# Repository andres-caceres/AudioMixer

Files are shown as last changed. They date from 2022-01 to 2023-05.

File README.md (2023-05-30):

# AudioMixer v1.2 (beta)
Digital audio USB controller firmware for Windows, tested using an Arduino Nano. Lets you control the volume of different applications using potentiometers and mute each channel individually using push button switches.
Based on [Deej by Omriharel], can be used with deej.exe Windows client.

## Features
* Includes mute push button functionality and ADC range calibration settings for each channel.
* Supports TM1637 7 segment display for controller position feedback.
* Supports LED push buttons for visual feedback.
* Uses digital filtering to increase potentiometer position accuracy.

## Upcoming (desired) Features
* Windows audio device selection using one push button press.
* Push buttons that can be used for executing Macros to automate tasks.
* Calibration subroutine for sliders

(Work in progress)

[//]: #

[Deej by Omriharel]: <https://github.com/omriharel/deej>

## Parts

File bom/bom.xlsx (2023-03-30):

 | Primer prototipo
No. | Item | Cantidad | Precio unit | Precio total | ¿Se tiene? | Costo total
1 | Resistencia 10k | 5 | S/0.10 | S/0.50 | NO | S/0.50
2 | LED Rojo | 3 | S/0.10 | S/0.30 | NO | S/0.30
3 | Transistor NPN 2N3904 | 2 | S/0.20 | S/0.40 | NO | S/0.40
4 | Encoder Rotativo | 1 | S/7.00 | S/7.00 | NO | S/7.00
 |  |  | Valor Total: | S/8.20 | Inversión Total: | S/8.20
 | Segundo prototipo
No. | Item | Cantidad | Precio unit | Precio total | ¿Se tiene? | Costo total
1 | Resistencia 10k | 5 | S/0.10 | S/0.50 | NO | S/0.50
2 | LED Rojo | 3 | S/0.10 | S/0.30 | NO | S/0.30
3 | Transistor NPN 2N3904 | 2 | S/0.20 | S/0.40 | NO | S/0.40
4 | Encoder Rotativo | 1 | S/7.00 | S/7.00 | NO | S/7.00
 |  |  | Valor Total: | S/8.20 | Inversión Total: | S/8.20

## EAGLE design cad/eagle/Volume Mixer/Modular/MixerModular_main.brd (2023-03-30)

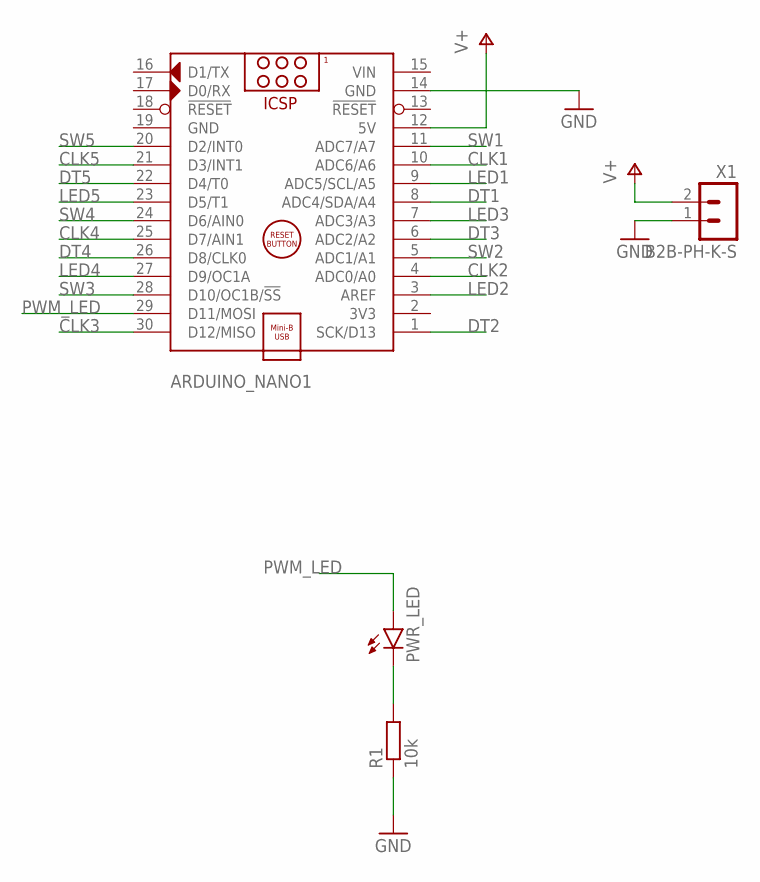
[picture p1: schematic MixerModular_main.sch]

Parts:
ARDUINO_NANO1: ARDUINO_NANO
PWR_LED: LED5MM
R1: 10k; 0207/10
X1: B2B-PH-K-S

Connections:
CLK1: ARDUINO_NANO1.10 (ADC6/A6)
CLK2: ARDUINO_NANO1.4 (ADC0/A0)
CLK3: ARDUINO_NANO1.30 (D12/MISO)
CLK4: ARDUINO_NANO1.25 (D7/AIN1)
CLK5: ARDUINO_NANO1.21 (D3/INT1)
DT1: ARDUINO_NANO1.8 (ADC4/SDA/A4)
DT2: ARDUINO_NANO1.1 (SCK/D13)
DT3: ARDUINO_NANO1.6 (ADC2/A2)
DT4: ARDUINO_NANO1.26 (D8/CLK0)
DT5: ARDUINO_NANO1.22 (D4/T0)
GND: ARDUINO_NANO1.14 (GND), ARDUINO_NANO1.19 (GND), R1.1, X1.1
LED1: ARDUINO_NANO1.9 (ADC5/SCL/A5)
LED2: ARDUINO_NANO1.3 (AREF)
LED3: ARDUINO_NANO1.7 (ADC3/A3)
LED4: ARDUINO_NANO1.27 (D9/OC1A)
LED5: ARDUINO_NANO1.23 (D5/T1)
unnamed: PWR_LED.K (C), R1.2
PWM_LED: ARDUINO_NANO1.29 (D11/MOSI), PWR_LED.A
SW1: ARDUINO_NANO1.11 (ADC7/A7)
SW2: ARDUINO_NANO1.5 (ADC1/A1)
SW3: ARDUINO_NANO1.28 (D10/OC1B/!SS)
SW4: ARDUINO_NANO1.24 (D6/AIN0)
SW5: ARDUINO_NANO1.20 (D2/INT0)
V+: ARDUINO_NANO1.12 (5V), X1.2
VIN: ARDUINO_NANO1.15 (VIN)

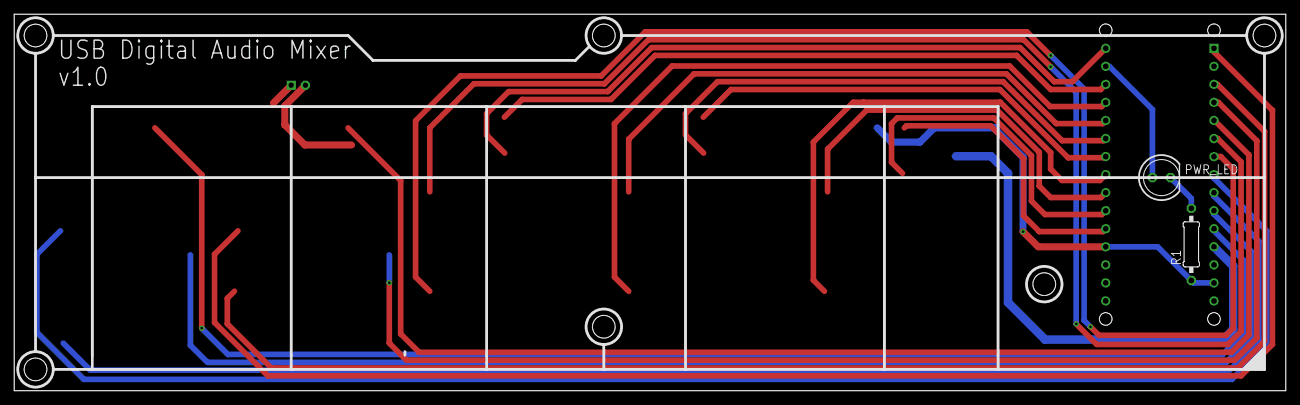
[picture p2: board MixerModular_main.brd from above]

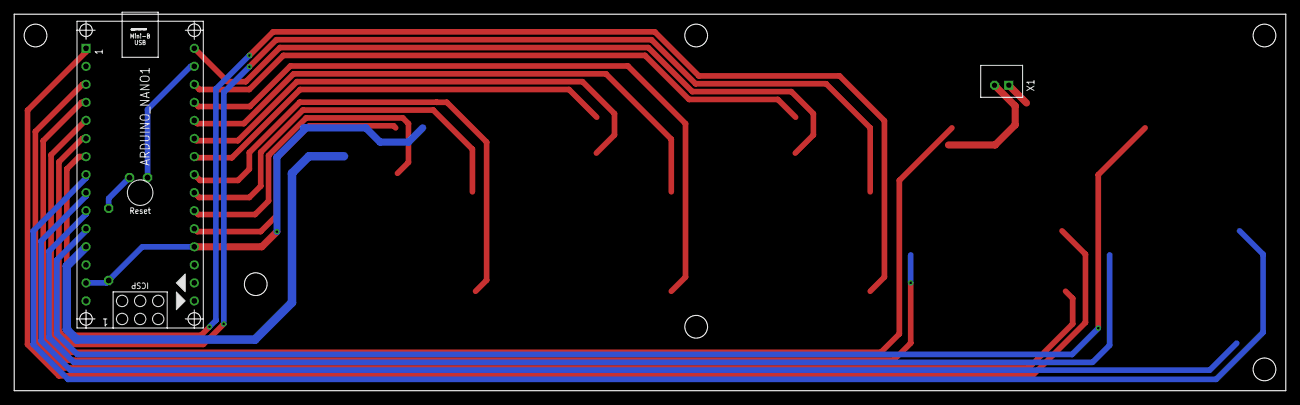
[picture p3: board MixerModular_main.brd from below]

Board: 2 copper layers, 179.0 x 53.0 mm, 4 parts (2 on the bottom side), 4 nets.

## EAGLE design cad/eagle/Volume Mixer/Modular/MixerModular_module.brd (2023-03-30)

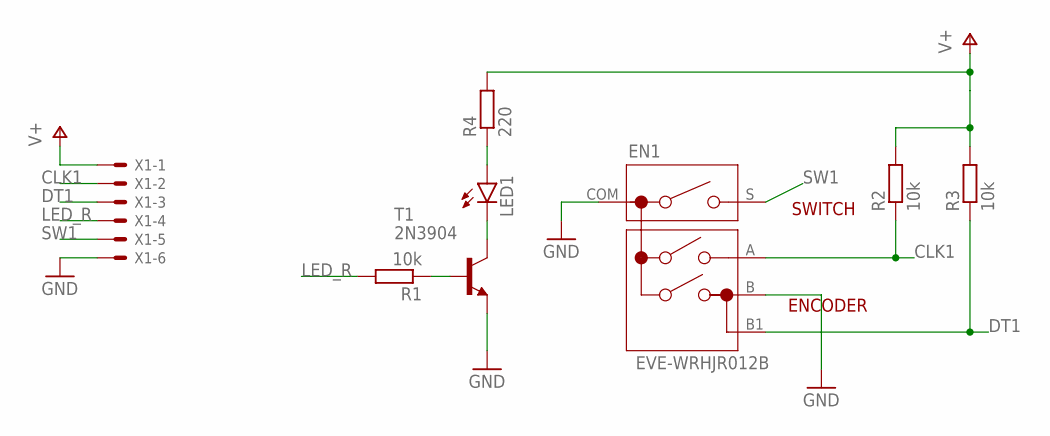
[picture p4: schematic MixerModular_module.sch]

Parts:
EN1: EVE-WRHJR012B
LED1: LED5MM
R1, R2, R3: 10k; 0207/10
R4: 220; 0207/10
T1: 2N3904; TO92
X1: 22-23-2061

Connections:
CLK1: EN1.A, R2.1, X1.2
DT1: EN1.B1, R3.1, X1.3
GND: EN1.B, EN1.COM, T1.3 (E), X1.6
LED_R: R1.2, X1.4
unnamed: LED1.A, R4.1
unnamed: R1.1, T1.2 (B)
unnamed: LED1.K (C), T1.1 (C)
SW1: EN1.S, X1.5
V+: R2.2, R3.2, R4.2, X1.1

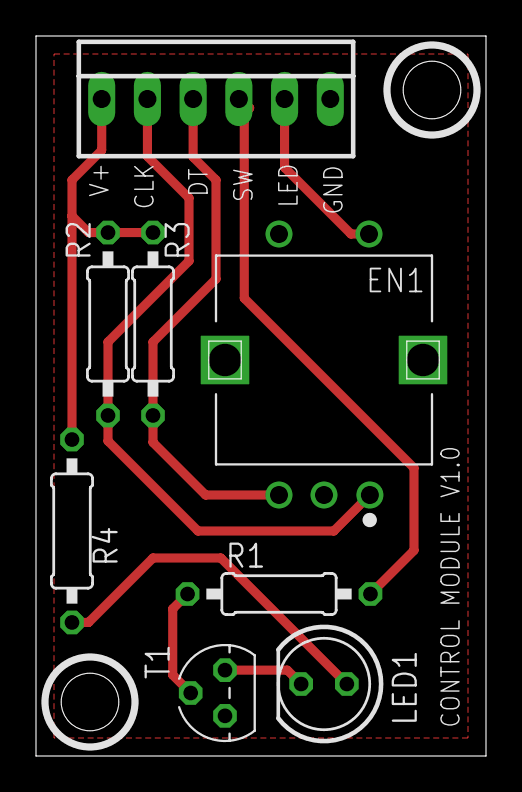
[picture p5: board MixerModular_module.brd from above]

Board: 2 copper layers, 25.0 x 40.0 mm, 8 parts (0 on the bottom side), 9 nets.

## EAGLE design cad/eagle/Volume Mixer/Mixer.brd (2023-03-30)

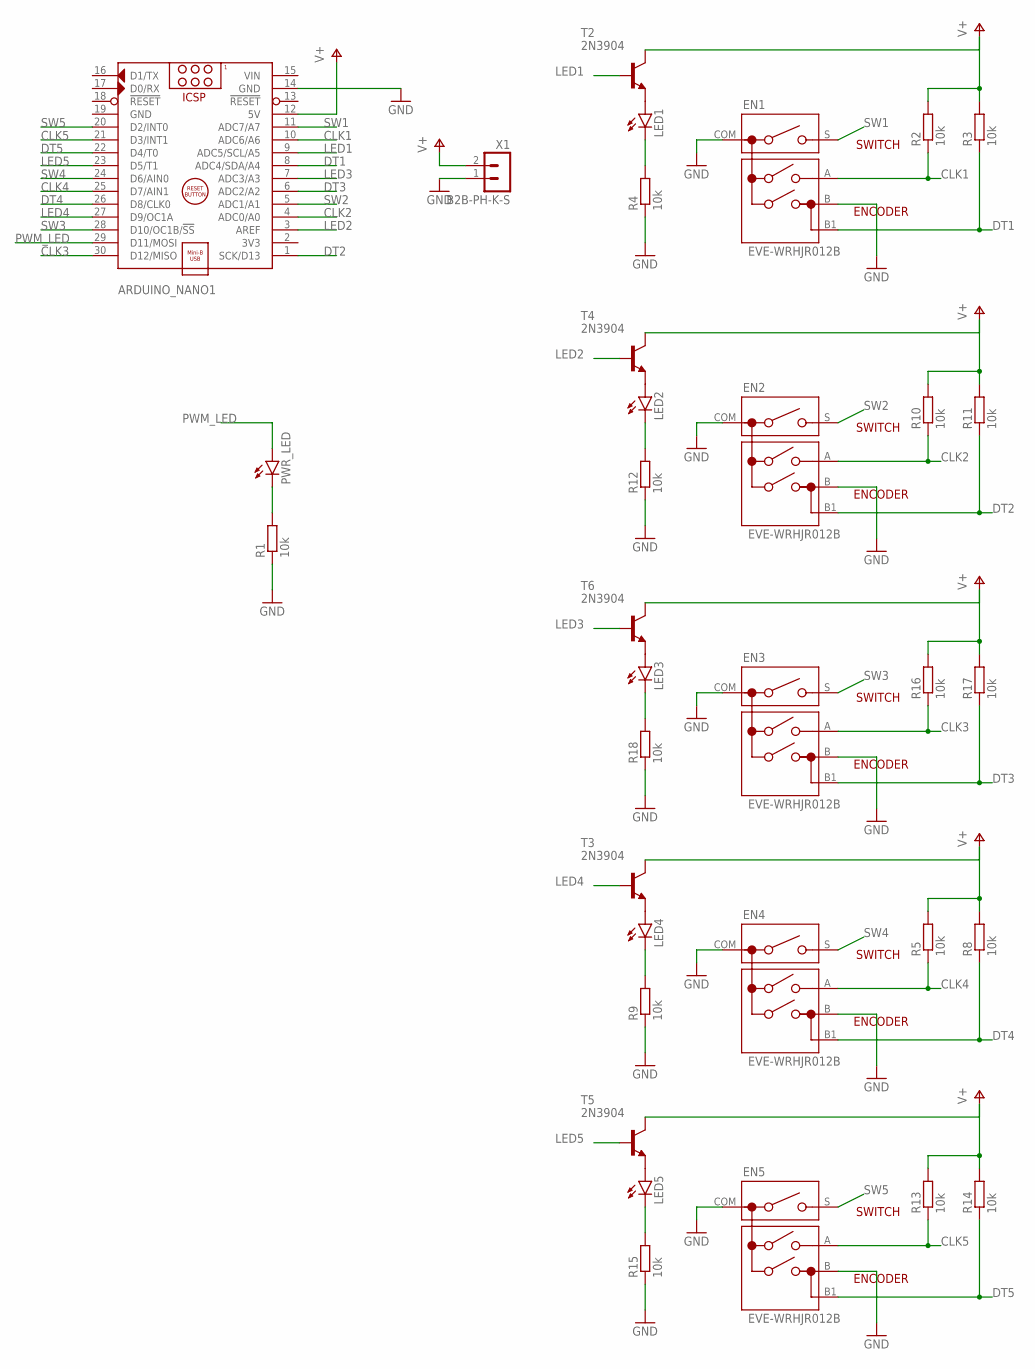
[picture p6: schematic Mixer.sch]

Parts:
ARDUINO_NANO1: ARDUINO_NANO
EN1, EN2, EN3, EN4, EN5: EVE-WRHJR012B
LED1, LED2, LED3, LED4, LED5: LED5MM
PWR_LED: LED5MM
R1, R2, R3, R4, R5, R8, R9, R10, R11, R12, R13, R14, R15, R16, R17, R18: 10k; 0207/10
T2, T3, T4, T5, T6: 2N3904; TO92
X1: B2B-PH-K-S

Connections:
CLK1: ARDUINO_NANO1.10 (ADC6/A6), EN1.A, R2.1
CLK2: ARDUINO_NANO1.4 (ADC0/A0), EN2.A, R10.1
CLK3: ARDUINO_NANO1.30 (D12/MISO), EN3.A, R16.1
CLK4: ARDUINO_NANO1.25 (D7/AIN1), EN4.A, R5.1
CLK5: ARDUINO_NANO1.21 (D3/INT1), EN5.A, R13.1
DT1: ARDUINO_NANO1.8 (ADC4/SDA/A4), EN1.B1, R3.1
DT2: ARDUINO_NANO1.1 (SCK/D13), EN2.B1, R11.1
DT3: ARDUINO_NANO1.6 (ADC2/A2), EN3.B1, R17.1
DT4: ARDUINO_NANO1.26 (D8/CLK0), EN4.B1, R8.1
DT5: ARDUINO_NANO1.22 (D4/T0), EN5.B1, R14.1
GND: ARDUINO_NANO1.14 (GND), ARDUINO_NANO1.19 (GND), EN1.B, EN1.COM, EN2.B, EN2.COM, EN3.B, EN3.COM, EN4.B, EN4.COM, EN5.B, EN5.COM, R1.1, R4.1, R9.1, R12.1, R15.1, R18.1, X1.1
LED1: ARDUINO_NANO1.9 (ADC5/SCL/A5), T2.2 (B)
LED2: ARDUINO_NANO1.3 (AREF), T4.2 (B)
LED3: ARDUINO_NANO1.7 (ADC3/A3), T6.2 (B)
LED4: ARDUINO_NANO1.27 (D9/OC1A), T3.2 (B)
LED5: ARDUINO_NANO1.23 (D5/T1), T5.2 (B)
unnamed: PWR_LED.K (C), R1.2
unnamed: LED1.K (C), R4.2
unnamed: LED1.A, T2.3 (E)
unnamed: LED4.K (C), R9.2
unnamed: LED4.A, T3.3 (E)
unnamed: LED2.K (C), R12.2
unnamed: LED2.A, T4.3 (E)
unnamed: LED5.K (C), R15.2
unnamed: LED5.A, T5.3 (E)
unnamed: LED3.K (C), R18.2
unnamed: LED3.A, T6.3 (E)
PWM_LED: ARDUINO_NANO1.29 (D11/MOSI), PWR_LED.A
SW1: ARDUINO_NANO1.11 (ADC7/A7), EN1.S
SW2: ARDUINO_NANO1.5 (ADC1/A1), EN2.S
SW3: ARDUINO_NANO1.28 (D10/OC1B/!SS), EN3.S
SW4: ARDUINO_NANO1.24 (D6/AIN0), EN4.S
SW5: ARDUINO_NANO1.20 (D2/INT0), EN5.S
V+: ARDUINO_NANO1.12 (5V), R2.2, R3.2, R5.2, R8.2, R10.2, R11.2, R13.2, R14.2, R16.2, R17.2, T2.1 (C), T3.1 (C), T4.1 (C), T5.1 (C), T6.1 (C), X1.2
VIN: ARDUINO_NANO1.15 (VIN)

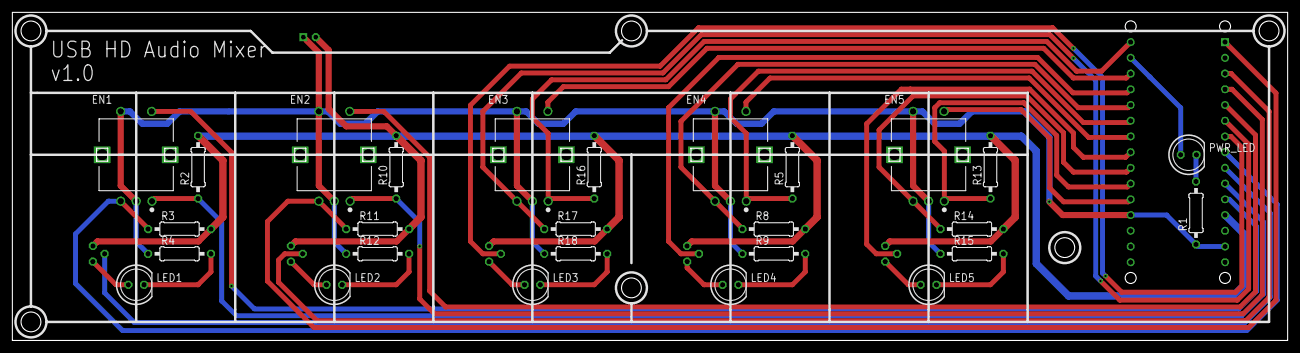
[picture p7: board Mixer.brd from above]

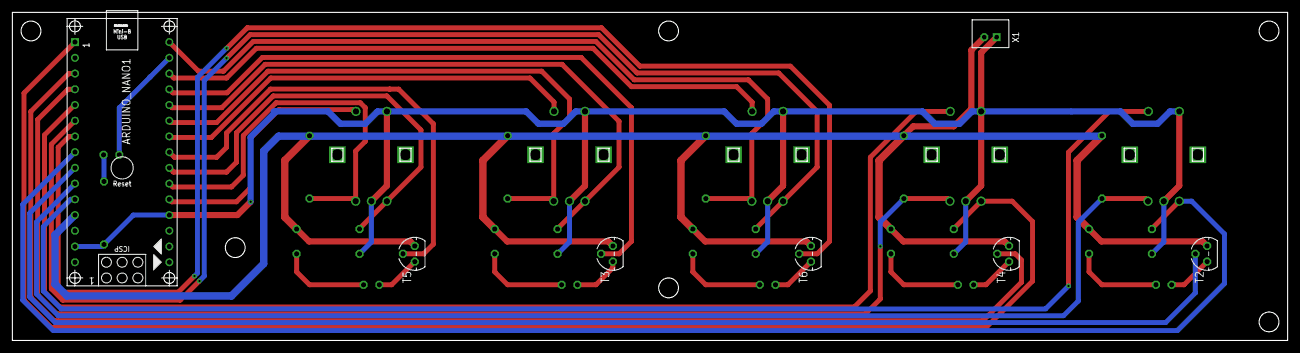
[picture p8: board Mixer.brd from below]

Board: 2 copper layers, 206.0 x 53.0 mm, 34 parts (7 on the bottom side), 34 nets.

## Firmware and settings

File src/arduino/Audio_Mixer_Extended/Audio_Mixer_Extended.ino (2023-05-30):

/*******************************
  AutoMixer Extended Firmware
  Based on deej by Omri Harel
  version: beta 1.2
*******************************/


#include <TM1637.h>
//#include <iostream>
#include <math.h>
//#include <EEPROM.h>

/*  Pinout */

#define SLIDER_0 A3 //A0
#define SLIDER_1 A2 //A1
#define SLIDER_2 A1 //A2
#define SLIDER_3 A0 //A3

#define MUTE_BTN_0 2 //D2
#define MUTE_BTN_1 4 //D4
#define MUTE_BTN_2 7 //D7
#define MUTE_BTN_3 8 //D8

#define ROTPOT_0 A4 //A4 //Master
#define ROTPOT_1 A5 //A5
#define ROTPOT_2 A6 //A6
#define ROTPOT_3 A7 //A7 

#define DEV_BTN_0 10 //D10
#define DEV_BTN_1 11 //D11
#define DEV_BTN_2 12 //D12

#define PWM_0 3 //D3
#define PWM_1 5 //D5
#define PWM_2 6 //D6

#define DISP_CLK 9 //D9
#define DISP_DIO 13 //D13

#define DEFAULT_BRIGHTNESS 3 //for screen

const uint16_t ADC_RESOLUTION = 1023; 
const uint8_t NUM_SLIDERS = 4; //and mute buttons
const uint8_t NUM_ROTPOT = 4;
const uint8_t NUM_INPUTS = NUM_SLIDERS + NUM_ROTPOT;
const uint8_t NUM_DEVBTN = 3; //and pwmLEDs
const unsigned int BLINK_PERIOD = 100; //ms
const unsigned int BLINK_TIMES_LIMIT = 5; //times

const int analogInputs[NUM_INPUTS] = {SLIDER_0, SLIDER_1, SLIDER_2, SLIDER_3, ROTPOT_0, ROTPOT_1, ROTPOT_2, ROTPOT_3};
const int muteBtns[NUM_SLIDERS] = {MUTE_BTN_0, MUTE_BTN_1, MUTE_BTN_2, MUTE_BTN_3};
const int devBtns[NUM_DEVBTN] = {DEV_BTN_0, DEV_BTN_1, DEV_BTN_2};
const int pwmLEDs[NUM_DEVBTN] = {PWM_0, PWM_1, PWM_2};

unsigned long blinkLastTime;
uint16_t times_blinked[NUM_DEVBTN];

//adc reading values
uint16_t analogValues[NUM_INPUTS];
bool  isMuted[NUM_INPUTS];
uint16_t lastAnalogValues[NUM_INPUTS];

//display
uint8_t previousValue[NUM_INPUTS];
unsigned long previousTime = 0;
unsigned long currentTime = 0;
const unsigned int DISPLAY_THRESHOLD = 2;    // set threshold for detecting ADC value change
const unsigned int DISPLAY_TIMEOUT = 3000;    // display threshold in seconds
bool isLocked[NUM_INPUTS] = {true,true,true,true,true,true,true,true};

//ExpAvgFilter
const float alpha = 0.2; //lower is slower
double lastAvg[NUM_INPUTS];

//max and min values for adc calibration
const uint16_t analogMaxValues[NUM_INPUTS] = {1009, 1009, 1009, 1009, 1021, 1021, 1021, 1021};
const uint16_t analogMinValues[NUM_INPUTS] = {30, 30, 30, 30, 0, 0, 0, 0};

//device button status
bool devBtnStatus[NUM_DEVBTN] = {0,0,0};
bool prevDevBtnStatus[NUM_DEVBTN] = {0,0,0};
int ledStatus[NUM_DEVBTN]; //status 0: off, 1:blink on, 2:blink off, 3: on

//leds
int brightness[NUM_DEVBTN]={255,255,255};

TM1637 tm(DISP_CLK, DISP_DIO);

void setup() {

  Serial.begin(19200);
  while(!Serial); //wait for serial ready
  Serial.println("Initializing...");

  //all sliders and pots
  for (int i = 0; i < NUM_INPUTS; i++) {
    pinMode(analogInputs[i], INPUT);
  }

  //mute btns
  for (int i = 0; i < NUM_SLIDERS; i++) {
    pinMode(muteBtns[i], INPUT);
  }

  //dev btns
  for (int i = 0; i < NUM_DEVBTN; i++) {
    pinMode(devBtns[i], INPUT);
  }

  //leds
  for (int i = 0; i < NUM_DEVBTN; i++) {
    pinMode(pwmLEDs[i], OUTPUT);
  }
  
  //Display
  pinMode(DISP_CLK, OUTPUT);
  pinMode(DISP_DIO, OUTPUT);

  tm.begin();
  tm.setBrightness(DEFAULT_BRIGHTNESS);
  Serial.println("IO Setup Complete");
  delay(100);
  Serial.println("Initializing Values..."); 
  initValues();
  Serial.println("Done");
  Serial.println("Running welcome animation...");
  //HelloWorld();
  Serial.println("Done");
  Serial.println("Streaming Data...");
}

void loop() {
  updateValues();
  updateScreen();
  updateDevBtnStatus();
  updateDevBtnLEDs2();
  //printInputValues();
  sendValues(); // Send data
  //delay(20);
}

void updateValues() {

  for (uint8_t i = 0; i < NUM_INPUTS; i++) {
    analogValues[i] = readADC(i);
  }
  
  //check for mute buttons
  for (uint8_t i = 0; i < NUM_SLIDERS; i++) {
    isMuted[i] = (bool) digitalRead(muteBtns[i]);
  }

  for (uint8_t i = NUM_SLIDERS+1; i < NUM_INPUTS; i++) {
    isMuted[i] = devBtnStatus[i-(NUM_SLIDERS+1)];
  }

}

void initValues() {

  for (uint8_t i = 0; i < NUM_SLIDERS; i++) {
    isMuted[i] = (bool) digitalRead(muteBtns[i]);
  }

  for (uint8_t i = NUM_SLIDERS+1; i < NUM_INPUTS; i++) {
    isMuted[i] = 0;
  }
  
  for(int j=0;j<40;j++){
    for (uint8_t i = 0; i < NUM_INPUTS; i++) {
      analogValues[i]=readADC(i);
      lastAnalogValues[i]= analogValues[i];
      previousValue[i]= getSliderPercent(i);
    }
  }
}

void sendValues() {
  String builtString = String("");

  for (int i = 0; i < NUM_INPUTS; i++) {
    builtString += String((int)(analogValues[i]*(int)(!isMuted[i]))); //affected by isMuted

    if (i < NUM_INPUTS - 1) {
      builtString += String("|");
    }
  }
  
  Serial.println(builtString);
}

void printInputValues() {
  for (int i = 0; i < NUM_INPUTS; i++) {
    String printedString = String("CH#") + String(i + 1) + String(": ") + String(" DISP=")+ String(getSliderPercent(i)) + String(" ADC=") + String(analogValues[i]);
    Serial.write(printedString.c_str());

    if (i < NUM_INPUTS - 1) {
      Serial.write(" | ");
    } else {
      Serial.write("\n");
    }
  }
}

void printDevBtnValues() {
  String builtString = String("");

  for (int i = 0; i < NUM_DEVBTN; i++) {
    builtString += String((bool)(devBtnStatus[i]));

    if (i < NUM_DEVBTN - 1) {
      builtString += String("|");
    }
  }

  Serial.println(builtString);
}

void printisMuted() {
  String builtString = String("");

  for (int i = 0; i < NUM_INPUTS; i++) {
    builtString += String(isMuted[i]);

    if (i < NUM_INPUTS - 1) {
      builtString += String("|");
    }
  }

  Serial.println(builtString);
}

void updateDevBtnStatus() {
  
   for (int i = 0; i < NUM_DEVBTN; i++) { //starts in i=1 because of hardware fault with devbutton 0    
    if(i==0){
      if(digitalRead(devBtns[i])==LOW) {
      
        digitalWrite(pwmLEDs[i],HIGH);
        while(digitalRead(devBtns[i])==LOW); //wait for release
        delay(10);
        
        devBtnStatus[i] = !devBtnStatus[i];
        ledStatus[i]=1;
      }      
    } else {
      if(digitalRead(devBtns[i])==HIGH) {
      
        digitalWrite(pwmLEDs[i],HIGH);
        while(digitalRead(devBtns[i])==HIGH); //wait for release
        delay(10);
        
        devBtnStatus[i] = !devBtnStatus[i];
        ledStatus[i]=1;
      }      
    }             
  }
}

void updateDevBtnLEDs () {
  
  for (int i = 0; i < NUM_DEVBTN; i++) {
      switch (ledStatus[i]) {
        case 0:  //led off
          digitalWrite(pwmLEDs[i],LOW);
          break;

        case 1:  //led blinking on          
          if (millis() >= (blinkLastTime+(BLINK_PERIOD))){
            ledStatus[i] = 2;
            blinkLastTime = millis();
            //Serial.print("blink off \n");
            }
          digitalWrite(pwmLEDs[i],HIGH);
          break;

        case 2: //led blinking off
          digitalWrite(pwmLEDs[i],LOW);
          if (millis() >= (blinkLastTime+(BLINK_PERIOD))) {
            ledStatus[i] = 1;
            blinkLastTime=millis();
            times_blinked[i]++;
            //Serial.print("blink off \n");
          }

          if (times_blinked[i]>=BLINK_TIMES_LIMIT) {
            ledStatus[i]= 3;
            times_blinked[i]=0;
          } //end blinking
          break;

        case 3:          
          // for (int j = 0; j < NUM_DEVBTN; i++) { //turn off all j leds
          //   ledStatus[j] = 0;
          //   digitalWrite(pwmLEDs[j],LOW);
          // }
          // blinkLastTime=millis();
          // ledStatus[i] = 3;  //except this one, i
          // digitalWrite(pwmLEDs[i],HIGH)
          digitalWrite(pwmLEDs[i],LOW);
        default:
          ledStatus[i]=0;
          break;
      }
    }
}

void updateDevBtnLEDs2 () {
  
  for(int i=0; i< NUM_DEVBTN; i++){    
    if(ledStatus[i]==1){
      if(brightness[i]>=0){
        analogWrite(pwmLEDs[i],brightness[i]);
        brightness[i]=brightness[i]-5;
      } else {        
        brightness[i]=255;
        ledStatus[i]=0;
      } 
    }
  }  
}

void HelloWorld() {
  
  //pwmledbtn welcome for 3 leds
  for(int i=0;i<NUM_DEVBTN;i++){brightness[i]=0;}//set brightness values to 0
  
  //start led sequence
  for(int i=NUM_DEVBTN-1;i>=0;i--){
    while(brightness[i]<80){      
      analogWrite(pwmLEDs[i],brightness[i]);
      brightness[i]++;
      delay(2);
    }
  }
  while(brightness[0]<=255){   
    for(int i=NUM_DEVBTN-1;i>=0;i--){
      analogWrite(pwmLEDs[i],brightness[i]);
      brightness[i]++;
      delay(2);
    }
  }
  for(int i=0;i<NUM_DEVBTN;i++){brightness[i]=255;} //reset brightness values to 255
  while(brightness[0]>0){   
    for(int i=NUM_DEVBTN-1;i>=0;i--){
      analogWrite(pwmLEDs[i],brightness[i]);
      brightness[i]--;
      delay(2);
    }
  }  
  for(int i=0;i<NUM_DEVBTN;i++){brightness[i]=255;} //reset brightness values to 255

  delay(10);
  digitalWrite(PWM_0,LOW);
  digitalWrite(PWM_1,LOW);
  digitalWrite(PWM_2,LOW);
  
  //start same led sequence 2 times
  // for (int j=0; j<2 ;j++){
  //   //reset brightness values to 0 and display values
  //   for(int i=0;i<NUM_DEVBTN;i++){ 
  //     brightness[i]=0;
  //     analogWrite(pwmLEDs[i],brightness[i]);
  //   }
  //   delay(4);
  //   //same led sequence but fast
  //   for(int i=NUM_DEVBTN-1;i>=0;i--){
  //     while(brightness[i]<80){      
  //       analogWrite(pwmLEDs[i],brightness[i]);
  //       brightness[i]++;
  //       delay(2);        
  //     }    
  //   }    
  // }  
  
  // welcome display animation
  int t = 60; //delay time
  const uint8_t rawBuffer[6][4] = {
    {DisplayDigit().setE(), 0x00, 0x00, DisplayDigit().setB()},
    {DisplayDigit().setF(), 0x00, 0x00, DisplayDigit().setC()},
    {DisplayDigit().setA(), 0x00, 0x00, DisplayDigit().setD()},
    {0x00, DisplayDigit().setA(), DisplayDigit().setD(), 0x00},
    {0x00, DisplayDigit().setD(), DisplayDigit().setA(), 0x00},
    {DisplayDigit().setD(), 0x00, 0x00, DisplayDigit().setA()},
    };
  auto d = DisplayDigit().setA().setE().setF().setD();
  const uint8_t ring[4] = {d, 0x09, DisplayDigit().setA().setD(), 15};
  const uint8_t dash[4] = {0x40, 0x40, 0x40, 0x40};
  tm.clearScreen();
  tm.setBrightness(2);
  //main display animation loop
  for(int i=0; i<60 ; i++){
    for(int j =0; j<2;j++){
      for(int k=0; k<6 ; k++){
        tm.displayRawBytes(rawBuffer[k], 4);
        delay(t);
      }
       if(t>=10){
        t=t-10;
      } else {
        if(t>=5){t--;}
      }
    }
  }
  //display end flash
  tm.setBrightness(1);
  tm.displayRawBytes(ring, 4);
  delay(60);
  tm.setBrightness(2);
  tm.displayRawBytes(ring, 4); 
  delay(40);
  tm.setBrightness(3);
  tm.displayRawBytes(ring, 4);
  delay(20);
  tm.setBrightness(4);
  tm.displayRawBytes(ring, 4);
  delay(20);
  tm.setBrightness(3);
  tm.displayRawBytes(dash, 4);
  delay(10);
  tm.setBrightness(1);
  tm.displayRawBytes(dash, 4);
  delay(10);
  tm.clearScreen();
  tm.setBrightness(DEFAULT_BRIGHTNESS);
}

uint16_t getSliderPercent (uint8_t i){

  uint32_t adc_value = analogValues[i];
  //uint16_t adc_max = analogMaxValues[i];
  //uint16_t adc_min = analogMinValues[i];
  //uint8_t disp_num = (((adc_value - adc_min + 5) * 100) / (adc_max - adc_min + 5)); //using 5 as an offset to get 100 with values lower than 1023 
  //if (disp_num > 100) { disp_num = 100;} // just to be safe
  //if (disp_num < 0) { disp_num = 0;} // just to be safe

  uint16_t disp_num = (adc_value*100)/1023;
  return disp_num;
}

// Exponential Moving Average filter implementation for i ADCs
double expMovingAverage(uint8_t i) {
  int cur_sample = 0;
  double cur_avg = 0.0;
  cur_sample = analogRead(analogInputs[i]);
  cur_avg = ((cur_sample*alpha) + (lastAvg[i])*(1-alpha));
  lastAvg[i] = cur_avg;
  delayMicroseconds(200);
  return lastAvg[i];
}

// Reades ADCs with i pin index and does a linear interpolation with max and min adc values
uint16_t readADC(uint8_t i){
  uint32_t adc_value = expMovingAverage(i);
  uint16_t adc_max = analogMaxValues[i];
  uint16_t adc_min = analogMinValues[i];
  uint16_t offset = 1;
  long reading = map(adc_value,adc_min+offset,adc_max,0,1023);
  if (reading > 1023) { reading = 1023;} // just to be safe
  if (reading < 0) { reading = 0;} // just to be safe
  return (uint16_t) reading;
}

// Reades ADCs with i pin index and does a linear interpolation with max and min adc values
uint16_t readADC_raw(uint8_t i){
  uint16_t adc_value = expMovingAverage(i);
  return (uint16_t) adc_value;
}

// Updates the TM1637 Screen when a display value changes, waits for screen timeout
void updateScreen(){
  for (int i = 0; i<NUM_INPUTS; i++){

    uint8_t num=getSliderPercent(i);    
    if (num != previousValue[i]){ //check for value change
    //display num
      if (!isMuted[i]){
        displayNumberAndCh(num,i+1);
      } else {
        displayMuted(i+1);
      }
    previousTime= millis();
    previousValue[i]= num;
    } else {
      currentTime = millis();
      if ((currentTime - previousTime) >= DISPLAY_TIMEOUT){ //check for inactivity timeout
        tm.clearScreen();
        tm.setDp(4);
      }
    }   
  }
}

void displayNumber(uint8_t num) {

    if (num<10){
      tm.display(num,true,true,3);    
    }
    else if(num<100){
      tm.display(num,true,true,2);    
    }
    else{
      tm.display(num,true,true,1);
    }
}

void displayNumberAndCh(uint16_t num, uint8_t ch) {

  String mystring = "";

  if (num<10){
    mystring = String(ch) + String("  ") + String(num);   
  }
  else if(num<100){
    mystring = String(ch) + String(" ") + String(num);    
  }
  else{
    mystring = String(ch) + String(num);      
  }
  tm.display(mystring,true,true,0);
}

void displayMuted(uint8_t ch){
  
  String mystring = String(ch) + String(" --");
  tm.display(mystring,true,true,0);
}

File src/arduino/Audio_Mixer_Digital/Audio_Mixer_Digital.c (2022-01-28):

/*******************************
  Audio Mixer Digital Firmware
  Based on deej by Omri Harel
  version: pre-alpha 1.0
*******************************/

#define DEBUG 0

const int NUM_ENCODERS = 5;
const int clkInputs[NUM_ENCODERS] = {A0, A1, A2, A3, A4};
const int dtInputs[NUM_ENCODERS] = {A0, A1, A2, A3, A4};
const int swInputs[NUM_ENCODERS] = {A0, A1, A2, A3, A4};

int values[NUM_ENCODERS];

void setup() { 
  for (int i = 0; i < NUM_ENCODERS; i++) {
    
    pinMode(clkInputs[i], INPUT);
    pinMode(dtInputs[i], INPUT);
    pinMode(swInputs[i], INPUT);
    
  }

  Serial.begin(9600);

  initWelcome();
}

void loop() {
  
  updateValues();
  sendValues(); // Actually send data (all the time)
  //printValues(); // For debug
  
  delay(10);
  //delay(1000); // For debug
}

void updateValues() {

  for (int i = 0; i < NUM_ENCODERS; i++) {

     currentStateCLK = digitalRead(clkInputs);
     
     if (currentStateCLK != previousStateCLK){
        
        if (digitalRead(inputDT) != currentStateCLK) {
            // Encoder is rotating counterclockwise
            value --;
        }
        else {
           // Encoder is rotating clockwise
            value ++;
        }

        if value>1023 {value=1023};
        if value<0    {value=0};

        values[i]=value;
     }

     //update previous state
     previousStateCLK = currentStateCLK;

  }
}

void sendValues() {
  String builtString = String("");

  for (int i = 0; i < NUM_ENCODERS; i++) {
    builtString += String((int)values[i]);

    if (i < NUM_ENCODERS - 1) {
      builtString += String("|");
    }
  }
  
  Serial.println(builtString);
}


void printValues() {
  for (int i = 0; i < NUM_ENCODERS; i++) {
    String printedString = String("Encoder #") + String(i + 1) + String(": ") + String(Values[i]) + String("u");
    Serial.write(printedString.c_str());

    if (i < NUM_ENCODERS - 1) {
      Serial.write(" | ");
    } else {
      Serial.write("\n");
    }
  }
}

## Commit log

2023-03-30 v0.1 for testing
    [Mixer.brd, Mixer.sch, MixerModular_main.brd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]
2023-04-07 startup sequence display animation, IIR filter tuning
2023-05-30 now slider value calibration is done at ADC reading level instead of the lcd display
